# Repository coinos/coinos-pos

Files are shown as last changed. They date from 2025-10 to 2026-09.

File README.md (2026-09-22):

# Coinos Point of Sale Terminal

This device is intended to be used by retail merchants who want to take Bitcoin payments.

When you enter a sale amount in dollars on the device, it will call the Coinos API to generate an invoice.

Once the invoice is paid, the device lights up and displays a checkmark.

You can scroll through past payments and see if tips were added.

This project was inspired by https://github.com/lnbits/lnpos but the software and hardware is different.

## Parts

- [Xiao Seeed ESP32 C3 Development Board](https://www.aliexpress.com/item/1005006979844970.html)
- [3x4 Matrix Switch Keyboard](https://www.aliexpress.com/item/1005007094229478.html)
- [1.54" 4PIN OLED](https://www.aliexpress.com/item/1005009132302307.html)
- [1800mAH LiPo Battery](https://www.aliexpress.com/item/1005009445456523.html)

Design files for the custom PCB and case are included in this repository.

## Setup

Firmware can be installed with a USB C cable either using Arduino IDE or arduino-cli or visit https://coinos.io/flash to flash from the web. The web flasher's "Flash latest release" button installs the firmware published at https://coinos.io/firmware/manifest.json without touching the device's wifi/token config.

To build and publish a new release to the site, run `./publish.sh` (expects a coinos-ui checkout at `~/coinos-ui` or `$COINOS_UI`), then commit and deploy coinos-ui.

Build locally with:

```
arduino-cli compile -b esp32:esp32:esp32c3:CDCOnBoot=cdc --build-property build.partitions=min_spiffs --build-path=build coinos-pos.ino -u -p /dev/ttyACM0
```

`CDCOnBoot=cdc` routes `Serial` to the XIAO's USB-C port so `cat /dev/ttyACM0` shows the device log.

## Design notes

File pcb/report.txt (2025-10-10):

Updated LED from LED to LED1.
Annotation complete.
Annotation complete.

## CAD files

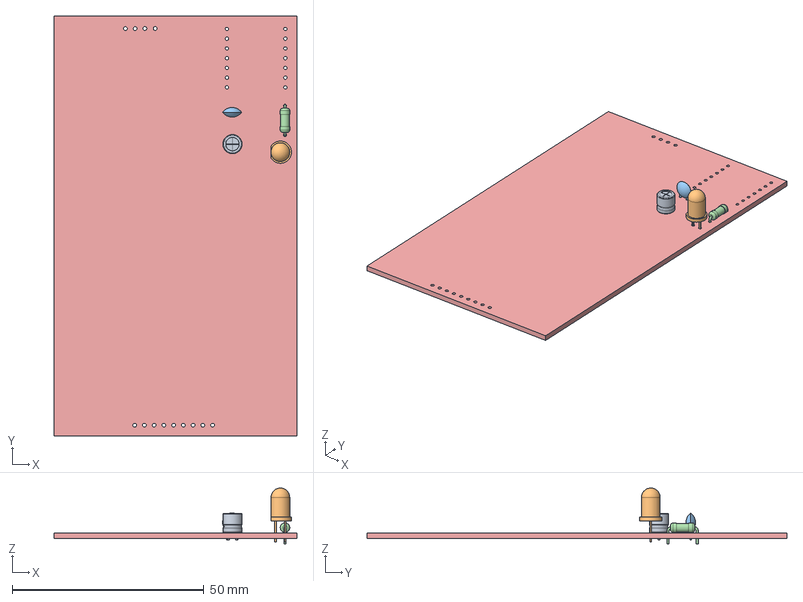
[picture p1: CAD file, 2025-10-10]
pcb/pos.step
63.3 x 109.5 x 14.6 mm
CP_Radial_D5.0mm_P2.00mm
LED_D5.0mm
C_Disc_D5.0mm_W2.5mm_P2.50mm
R_Axial_DIN0207_L6.3mm_D2.5mm_P7.62mm_Horizontal
pos_PCB

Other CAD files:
pcb/pos.stl

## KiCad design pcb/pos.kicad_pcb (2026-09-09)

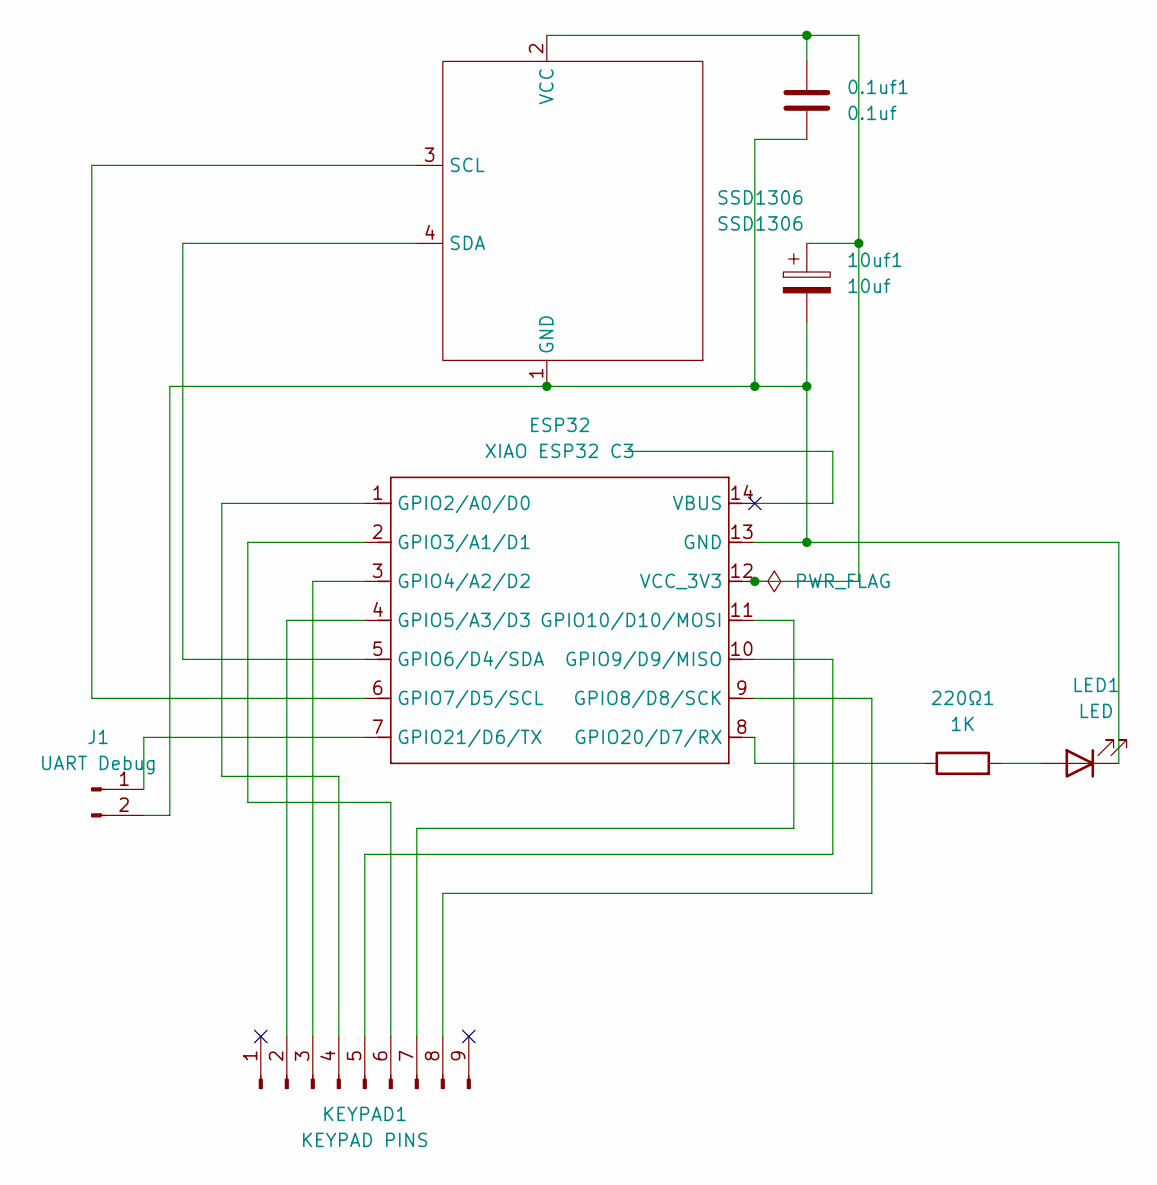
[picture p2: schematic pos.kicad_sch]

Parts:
0.1uf1: 0.1uf; C_Disc_D5.0mm_W2.5mm_P2.50mm
10uf1: 10uf; CP_Radial_D5.0mm_P2.00mm
220Ω1: 1K; R_Axial_DIN0207_L6.3mm_D2.5mm_P7.62mm_Horizontal
ESP32: XIAO ESP32 C3; XIAO-ESP32C3-DIP
J1: UART Debug; PinHeader_1x02_P2.54mm_Vertical
KEYPAD1: KEYPAD PINS; Keypad
LED1: LED; LED_D5.0mm
SSD1306: SSD1306; SD1306

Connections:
unnamed: 0.1uf1.2, 10uf1.2, ESP32.13 (GND), J1.2, LED1.1 (K), SSD1306.1 (GND)
unnamed: ESP32.1 (GPIO2/A0/D0), KEYPAD1.4
unnamed: ESP32.2 (GPIO3/A1/D1), KEYPAD1.6
unnamed: ESP32.3 (GPIO4/A2/D2), KEYPAD1.3
unnamed: ESP32.4 (GPIO5/A3/D3), KEYPAD1.2
unnamed: ESP32.5 (GPIO6/D4/SDA), SSD1306.4 (SDA)
unnamed: ESP32.6 (GPIO7/D5/SCL), SSD1306.3 (SCL)
unnamed: ESP32.9 (GPIO8/D8/SCK), KEYPAD1.8
unnamed: ESP32.10 (GPIO9/D9/MISO), KEYPAD1.5
unnamed: ESP32.11 (GPIO10/D10/MOSI), KEYPAD1.7
unnamed: 220Ω1.1, ESP32.8 (GPIO20/D7/RX)
unnamed: ESP32.7 (GPIO21/D6/TX), J1.1
unnamed: 0.1uf1.1, 10uf1.1, ESP32.12 (VCC_3V3), SSD1306.2 (VCC)
unnamed: 220Ω1.2, LED1.2 (A)

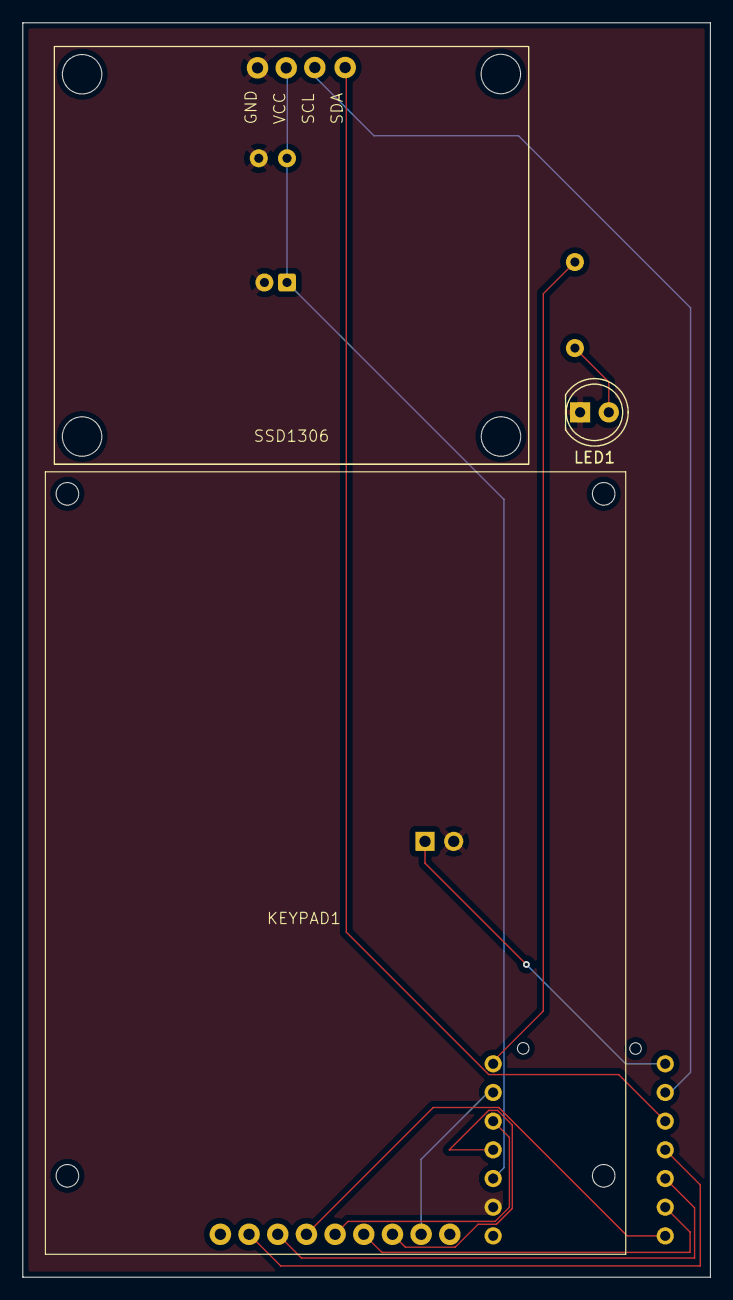
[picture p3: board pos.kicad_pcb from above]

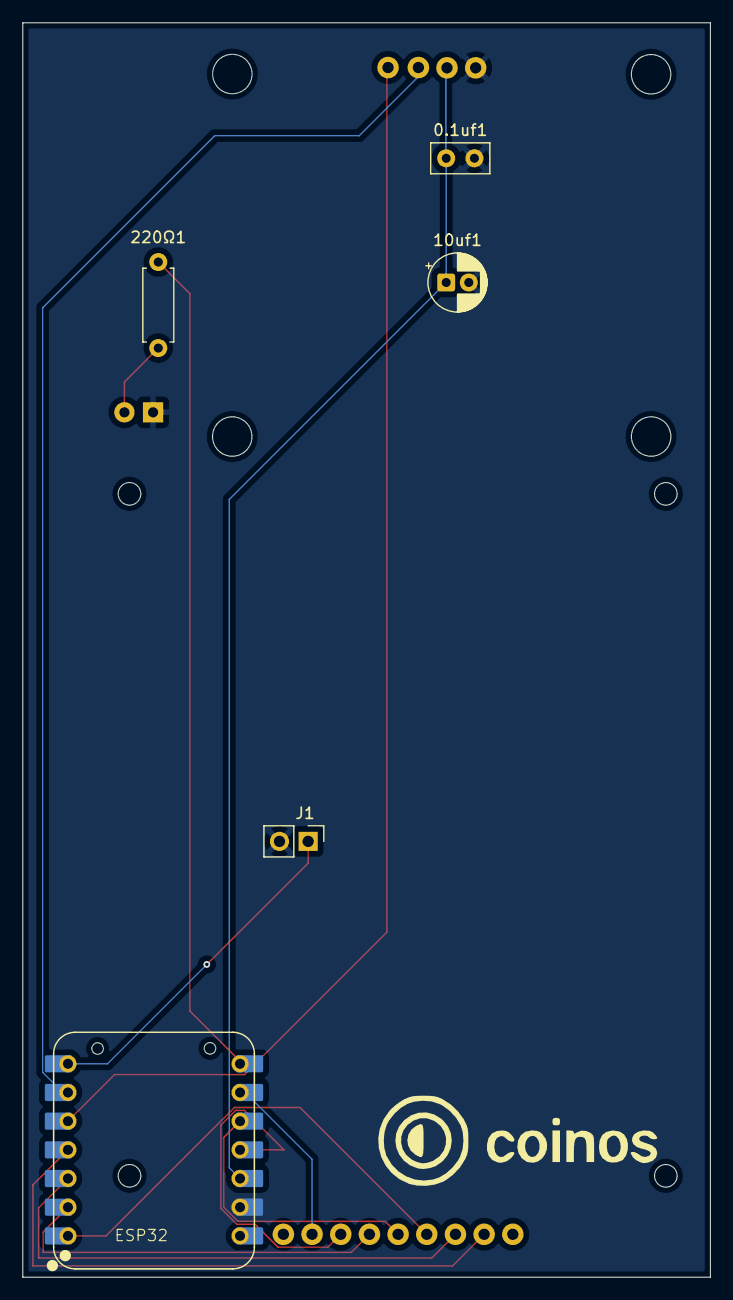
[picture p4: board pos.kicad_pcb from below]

Board: 4 copper layers, 60.9 x 111.1 mm, 8 parts (5 on the bottom side), 14 nets.

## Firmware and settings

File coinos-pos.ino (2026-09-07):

#include <Arduino.h>
#include <Wire.h>
#include <Keypad.h>
#include <WiFi.h>
#include <LittleFS.h>
#include <Adafruit_GFX.h>
#include <Adafruit_SH110X.h>
#include "config.h"
#include "ui.h"
#include "checkmark.h"
#include "storage.h"
#include "wifi_net.h"
#include "payments.h"
#include "nfc.h"
#include "ws.h"
#include "esp_sleep.h"
#include "driver/gpio.h"

// ---- Globals from UI ----
Adafruit_SH1106G display(SCREEN_WIDTH, SCREEN_HEIGHT, &Wire, OLED_RESET_PIN);

// ---- Keypad ----
Keypad keypad = Keypad(makeKeymap(KEYS), (byte*)ROW_PINS, (byte*)COL_PINS, ROWS, COLS);

// ---- State ----
Credentials creds;
String token;
String merchantLnurl;
uint64_t cents = 0;
uint64_t submittedCents = 0;
uint8_t digitsTyped = 0;
String lineStr = "";
String currentInvoiceId = "";
String currentInvoiceFiat = "";
bool invoicePaid = false;


// Auto-submit after 5 seconds of no digit changes
const unsigned long AUTO_SUBMIT_DELAY_MS = 2000;

unsigned long lastAmountChange = 0;
bool autoSubmitDoneForCurrentAmount = false;

Payment history[10];
int historyCount = 0;
int historyIndex = -1;

unsigned long lastHeartbeat = 0;
unsigned long lastActivity = 0;
bool isAsleep = false;

unsigned long lastLog = 0;
const unsigned long LOG_INTERVAL = 5000;

inline void touchActivity() { lastActivity = millis(); }

inline void showAmount(const char* header=nullptr) {
  lineStr = String("$") + formatCents(cents);
  renderLine(lineStr, header);
}

void goToSleep() {
  // Power down peripherals
  oledCommand(0xAE);
  digitalWrite(LED_GREEN_PIN, LOW);
  WiFi.disconnect(true, true);
  WiFi.mode(WIFI_OFF);

  // 1) Bias the keypad for deep sleep:
  //    rows -> OUTPUT LOW (held low during deep sleep)
  for (int i = 0; i < ROWS; ++i) {
    int rp = ROW_PINS[i];
    pinMode(rp, OUTPUT);
    digitalWrite(rp, LOW);
    gpio_hold_en((gpio_num_t)rp);
  }
  gpio_deep_sleep_hold_en();   // enable global hold for held pins

  //    columns -> INPUT_PULLUP (idle HIGH; press pulls LOW via row=LOW)
  for (int i = 0; i < COLS; ++i) {
    pinMode(COL_PINS[i], INPUT_PULLUP);
  }

  // 2) Deep-sleep GPIO wake on every column that can (GPIO0-5 on the C3)
  uint64_t wakeMask = 0;
  for (int i = 0; i < COLS; ++i) {
    int g = COL_PINS[i];
    if (g <= 5) wakeMask |= (1ULL << g);
  }
  esp_deep_sleep_enable_gpio_wakeup(wakeMask, ESP_GPIO_WAKEUP_GPIO_LOW);

  // 3) Also wake every 24 hours
  esp_sleep_enable_timer_wakeup(24ULL * 60ULL * 60ULL * 1000000ULL);

  Serial.println("SLEEP (deep: GPIO 3/5 + 24h)");
  esp_deep_sleep_start();   // never returns
}

void wakeFromSleep() {
  oledCommand(0xAF);
  delay(1);
  display.clearDisplay();
  renderLine("Keypad Ready");
  isAsleep = false;
  lastActivity = millis();
  Serial.println("WAKE");
}

void resetAll() {
  digitalWrite(LED_GREEN_PIN, LOW);
  cents = 0;
  digitsTyped = 0;
  if (currentInvoiceId != "") ws_disconnect();
  currentInvoiceId = "";
  invoicePaid = false;
  historyIndex = -1;
  showAmount("*:Back   #:Enter");

  autoSubmitDoneForCurrentAmount = false;
  lastAmountChange = millis();
}

void renderPayment() {
  if (historyCount == 0) { renderLine("", "No history"); return; }
  if (historyIndex < 0) historyIndex = historyCount - 1;
  if (historyIndex >= historyCount) historyIndex = 0;

  Payment &p = history[historyIndex];

  // Convert sats → fiat cents
  uint64_t satsPaid   = (uint64_t)(p.amount < 0 ? 0 : p.amount);
  uint64_t centsPaid  = roundCentsU64(satsPaid, p.rate);

  uint64_t satsTip    = (uint64_t)(p.tip < 0 ? 0 : p.tip);
  uint64_t centsTip   = roundCentsU64(satsTip, p.rate);

  // Header: local-ish time (keeps your original offset)
  time_t t = (p.created / 1000) - 25200;
  struct tm *createdTime = gmtime(&t);
  char dateString[32], timeString[16], header[48];
  const char* monthAbbrev[] = {"Jan","Feb","Mar","Apr","May","Jun","Jul","Aug","Sep","Oct","Nov","Dec"};
  snprintf(dateString, sizeof(dateString), "%s %d, %d",
           monthAbbrev[createdTime->tm_mon],
           createdTime->tm_mday,
           createdTime->tm_year + 1900);
  int h12 = createdTime->tm_hour % 12; if (h12 == 0) h12 = 12;
  snprintf(timeString, sizeof(timeString), "%d:%02d%s",
           h12, createdTime->tm_min,
           (createdTime->tm_hour < 12) ? "am" : "pm");
  snprintf(header, sizeof(header), "%s %s", dateString, timeString);

  String amountStr = "$" + formatCents(centsPaid);
  String tipStr    = centsTip > 0 ? " +$" + formatCents(centsTip) : "";

  int16_t x1, y1; uint16_t w, hgt;

  display.clearDisplay();
  display.setCursor(0, 0);
  display.setTextSize(1);
  display.print(header);

  display.setTextSize(2);
  display.setCursor(4, 24);
  display.print(amountStr); 

  display.getTextBounds(amountStr.c_str(), 0, 0, &x1, &y1, &w, &hgt);
  display.setTextSize(1);
  display.setCursor(w, 28);
  display.print(tipStr); 

  display.display();
}

bool fetchPayments() {
  if (!ensureWifiConnected(creds, 5000, []() { return keypad.getKey() == '*'; }, 800)) return false;

  HTTPClient http;
  http.setConnectTimeout(3000);
  http.setTimeout(3000);
  http.begin(String(API_HOST) + "/payments?limit=10&received=true");
  http.addHeader("Content-Type", "application/json");
  http.addHeader("Authorization", "Bearer " + token);

  int code = http.GET();
  if (code == HTTP_CODE_OK) {
    String payload = http.getString();
    http.end();

    StaticJsonDocument<256> filter;
    JsonArray flist = filter["payments"].to<JsonArray>();
    JsonObject f = flist.createNestedObject();
    f["id"]=true; f["amount"]=true; f["tip"]=true; f["created"]=true; f["currency"]=true; f["rate"]=true;
    filter["count"]=true;

    StaticJsonDocument<4096> doc;
    auto err = deserializeJson(doc, payload, DeserializationOption::Filter(filter));
    if (err) { Serial.print("payments JSON error: "); Serial.println(err.f_str()); return false; }

    JsonArray arr = doc["payments"].as<JsonArray>();
    historyCount = 0;
    for (JsonObjectConst p : arr) {
      if (historyCount >= (int)(sizeof(history)/sizeof(history[0]))) break;
      Payment &out = history[historyCount++];
      out.id       = p["id"]       | "";
      out.amount   = p["amount"]   | 0LL;
      out.tip      = p["tip"]      | 0LL;
      out.created  = p["created"]  | 0ULL;
      out.currency = p["currency"] | "";
      out.rate     = p["rate"]     | 0.0;
    }
    return true;
  } else {
    http.end();
    return false;
  }
}

void submitInvoice() {
  if (digitsTyped == 0) {
    if (historyIndex < 0) { 
      fetchPayments(); 
      if (historyCount > 0) historyIndex = historyCount - 1; 
    }
    else if (historyCount > 0) historyIndex = (historyIndex - 1 + historyCount) % historyCount;
    renderPayment();
    return;
  }

  String fiat = formatCents(cents);
  if (fiat.toFloat() <= 0 || currentInvoiceId != "") { resetAll(); return; }

  // Bounded: a terminal carried out of wifi range must fail fast and hand
  // the keypad back, not sit on "Submitting..." (it once sat there for the
  // better part of a minute). Worst case here is about 10s — 3s wifi, 3s
  // connect, 3s response — and * cancels the wifi wait.
  if (!ensureWifiConnected(creds, 3000, []() { return keypad.getKey() == '*'; }, 800)) return;

  renderLine(lineStr, "Submitting...");
  submittedCents = cents;

  HTTPClient http;
  http.setConnectTimeout(3000);
  http.setTimeout(3000);
  http.begin(String(API_HOST) + "/invoice");
  http.addHeader("Content-Type", "application/json");
  http.addHeader("Authorization", "Bearer " + token);

  String json = "{\"invoice\":{\"fiat\":\"" + fiat + "\"}}";
  int code = http.POST(json);

  if (code > 0) {
    String payload = http.getString();
    StaticJsonDocument<64> filter; filter["id"] = true;
    DynamicJsonDocument doc(4096);
    auto err = deserializeJson(doc, payload, DeserializationOption::Filter(filter));
    if (!err && doc["id"]) {
      currentInvoiceFiat = fiat;
      currentInvoiceId = (const char*)doc["id"];
      invoicePaid = false;
      ws_connect();
      ws_subscribe(currentInvoiceId);
      renderLine(lineStr, "Waiting for payment..");
    } else {
      renderLine(lineStr, "Invoice error"); delay(800);
    }
  } else {
    renderLine(lineStr, "Submit failed"); delay(800);
  }
  http.end();
}

void handlePayment(long long amount, long long tipSats) {
  if (currentInvoiceId == "" || invoicePaid) return;

  lastActivity = millis();
  invoicePaid = true;
  ws_disconnect();
  digitalWrite(LED_GREEN_PIN, HIGH);

  String header = "$" + currentInvoiceFiat;
  if (tipSats > 0 && submittedCents > 0) {
    double centsPerSat = (double)submittedCents / (double)amount;
    unsigned long long tipCents =
      (unsigned long long) llround((double)tipSats * centsPerSat);
    header += "+$" + formatCents(tipCents);
  }
  startCheckmarkAnimation(header.c_str());
}

// ---- Key handling ----
void onKey(char k) {
  if (isAsleep) wakeFromSleep();

  if (k == '*') {
    // Backspace / history browse
    if (digitsTyped == 0) {
      if (historyIndex < 0) { 
        fetchPayments(); 
        if (historyCount > 0) historyIndex = 0; 
      }
      else if (historyCount > 0) historyIndex = (historyIndex + 1) % historyCount;
      renderPayment();
      return;
    }

    // Backspace a digit
    cents /= 10; 
    digitsTyped--; 
    showAmount("*:Back   #:Enter");
    digitalWrite(LED_GREEN_PIN, LOW);
    currentInvoiceId = ""; 
    invoicePaid = false;

    // amount changed -> reset auto-submit timer
    lastAmountChange = millis();
    autoSubmitDoneForCurrentAmount = false;

    return;
  }

  if (k == '#') {
    digitalWrite(LED_GREEN_PIN, LOW);
    if (currentInvoiceId != "" || invoicePaid) { 
      resetAll(); 
      return; 
    }
    // manual submit: mark as done for this amount
    autoSubmitDoneForCurrentAmount = true;
    submitInvoice();
    return;
  }

  if (k >= '0' && k <= '9') {
    // New digit
    if (currentInvoiceId != "" || invoicePaid) resetAll();
    if (digitsTyped < MAX_DIGITS) {
      uint8_t v = (uint8_t)(k - '0');
      cents = cents * 10 + v;
      digitsTyped++;
      showAmount("*:Back   #:Enter");

      // amount changed -> reset auto-submit timer
      lastAmountChange = millis();
      autoSubmitDoneForCurrentAmount = false;
    }
  }
}

void setup() {
  Serial.begin(115200);
  delay(50);

  if (!LittleFS.begin()) Serial.println("LittleFS mount error");

  gpio_deep_sleep_hold_dis();
  for (int i = 0; i < ROWS; ++i) {
    gpio_hold_dis((gpio_num_t)ROW_PINS[i]);
  }

  // (Optional) check why we woke
  auto cause = esp_sleep_get_wakeup_cause();
  if (cause == ESP_SLEEP_WAKEUP_TIMER) {
    // quick maintenance: WiFi on -> check updates -> WiFi off -> sleep again if idle
  }

  // Load creds (token included in file’s 3rd line)
  if (readCredentials(creds)) {
    token = creds.token;
  } else {
    token = "";
  }

  ui_begin();
  nfc_begin();  // PN532 on shared I2C bus (addr 0x24)
  pinMode(LED_GREEN_PIN, OUTPUT);

  // Fetch username from API to derive LNURL for NFC
  if (token.length() > 0 && ensureWifiConnected(creds, 20000)) {
    HTTPClient http;
    http.begin(String(API_HOST) + "/me");
    http.addHeader("Authorization", "Bearer " + token);
    int code = http.GET();
    if (code == HTTP_CODE_OK) {
      StaticJsonDocument<64> filter; filter["username"] = true;
      StaticJsonDocument<256> doc;
      auto err = deserializeJson(doc, http.getString(), DeserializationOption::Filter(filter));
      if (!err && doc["username"]) {
        String username = (const char*)doc["username"];
        merchantLnurl = nfc_deriveLnurl(username);
        Serial.printf("Merchant: %s\n", username.c_str());
      }
    }
    http.end();

    // Prepare websocket for payment notifications (connects on invoice submit)
    onPaymentReceived = handlePayment;
    ws_init(token);
  }

  resetAll();
  lastActivity = millis();
}

void loop() {
  // Keypad: full-matrix scan so a chord can be recognised. A press is held
  // for a short window before it acts, so the second key of a chord can join
  // it — otherwise # alone would submit a sale before *+# was seen. * and #
  // share a row on different columns, which a diode-less 4x3 matrix reads
  // cleanly (ghosting needs two keys in each of two rows and two columns).
  static char pendingKey = 0;
  static unsigned long pendingAt = 0;
  const unsigned long CHORD_WINDOW_MS = 120;
  if (keypad.getKeys()) {
    for (int i = 0; i < LIST_MAX; i++) {
      Key &k = keypad.key[i];
      if (k.kchar == NO_KEY || !k.stateChanged || k.kstate != PRESSED) continue;
      if (pendingKey) {
        auto chord = [&](char a, char b) {
          return (pendingKey == a && k.kchar == b) || (pendingKey == b && k.kchar == a);
        };
        if (chord('*', '#')) {
          // *+# together: reboot (a stuck terminal has no other way out)
          renderLine("", "Rebooting..");
          delay(300);
          ESP.restart();
        }
        if (chord('0', '#')) {
          // 0+# together: sleep now, exactly as the idle timeout would.
          // A held key pulls its column low, which is the wake source, so
          // wait for both to be released first.
          renderLine("", "Sleeping..");
          unsigned long t0 = millis();
          while (millis() - t0 < 3000) {
            keypad.getKeys();
            bool down = false;
            for (int j = 0; j < LIST_MAX; j++) {
              Key &kk = keypad.key[j];
              if (kk.kchar != NO_KEY && (kk.kstate == PRESSED || kk.kstate == HOLD)) down = true;
            }
            if (!down) break;
            delay(10);
          }
          delay(50);
          goToSleep(); // never returns
        }
        onKey(pendingKey); touchActivity();
      }
      pendingKey = k.kchar;
      pendingAt = millis();
    }
  }
  if (pendingKey && millis() - pendingAt >= CHORD_WINDOW_MS) {
    char key = pendingKey;
    pendingKey = 0;
    onKey(key); touchActivity();
  }

  // Throttled debug
  if (millis() - lastLog >= LOG_INTERVAL) {
    lastLog = millis();
    Serial.printf("idle(ms): %lu  wifi: %s ssid=%s ip=%s\n",
                  millis() - lastActivity,
                  WiFi.status() == WL_CONNECTED ? "up" : "down",
                  creds.ssid.c_str(), WiFi.localIP().toString().c_str());
  }

  unsigned long now = millis();
  unsigned long idle = now - lastActivity;
  unsigned long timeout = (currentInvoiceId == "")
      ? INACTIVITY_NO_INVOICE_MS
      : INACTIVITY_WITH_INVOICE_MS;

  if (!isAsleep) {
    // Is there an amount on screen that we intend to auto-submit?
    bool pendingAutoSubmit =
      (currentInvoiceId == "" && !invoicePaid &&
       digitsTyped > 0 && !autoSubmitDoneForCurrentAmount);

    // --- AUTO-SUBMIT IF AMOUNT UNCHANGED FOR 5s ---
    if (pendingAutoSubmit &&
        (now - lastAmountChange) >= AUTO_SUBMIT_DELAY_MS) {

      autoSubmitDoneForCurrentAmount = true;
      submitInvoice();
      touchActivity(); // so we don't immediately go to sleep
      // NOTE: after this, currentInvoiceId should be non-empty on success,
      // so pendingAutoSubmit will be false on the next loop iteration.
    }
    // ----------------------------------------------

    // NFC: emulate tag with merchant's LNURL while invoice is active
    if (currentInvoiceId != "" && !invoicePaid && merchantLnurl.length() > 0) {
      nfc_emulate(merchantLnurl.c_str());
      if (nfc_poll()) touchActivity();
    } else {
      nfc_stop();
    }

    if (CM.active) {
      renderCheckmarkFrame();
    } else if (idle >= timeout && !pendingAutoSubmit) {
      // Only sleep if there's no auto-submit waiting to happen
      goToSleep();
    }
  }

  // Process websocket events and send heartbeat
  ws_loop();
  if (wsEnabled && now - lastHeartbeat >= 2000) {
    lastHeartbeat = now;
    ws_heartbeat();
  }

  delay(1);
}

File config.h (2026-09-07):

#pragma once

// ===== Hardware config =====
#define LED_GREEN_PIN      20          // your existing pin

// I2C / OLED
#define I2C_SDA_PIN        6
#define I2C_SCL_PIN        7
#define I2C_ADDRESS        0x3C
#define SCREEN_WIDTH       132
#define SCREEN_HEIGHT      64
#define OLED_RESET_PIN     -1

// Keypad. Deep sleep wakes on a COLUMN pulled low, and on the ESP32-C3 only
// GPIO0-5 can wake the chip, so every column should live on one of those.
//   BOARD_REV 1: the first PCB run. Column 0 (keys 1 4 7 *) is on GPIO10
//     and cannot wake the terminal from sleep.
//   BOARD_REV 2: pcb/pos.kicad_sch from 2026-09-07 on — keypad pin 4 and
//     pin 7 swapped between GPIO2 and GPIO10, so every key wakes it.
#ifndef BOARD_REV
#define BOARD_REV 1
#endif
#define ROWS 4
#define COLS 3
#if BOARD_REV >= 2
static const byte ROW_PINS[ROWS] = {4, 8, 10, 9};
static const byte COL_PINS[COLS] = {2, 5, 3};
#else
static const byte ROW_PINS[ROWS] = {4, 8, 2, 9};
static const byte COL_PINS[COLS] = {10, 5, 3};
#endif
static const char KEYS[ROWS][COLS] = {
  {'1','2','3'},
  {'4','5','6'},
  {'7','8','9'},
  {'*','0','#'}
};

// API — the coinos v3 name registrar's POS endpoints (names/server.js in
// coinosv3). The token in config.txt is a POS token minted by the merchant's
// wallet (Settings → payment address → Point of sale), scoped to one name:
// it can ring up sales and watch them settle, never spend.
static const char* API_HOST = "https://names.coinos.io/pos";
#define POS_WS_HOST "names.coinos.io"
#define POS_WS_PATH "/pos/ws"
#define POS_LNURL_BASE "https://names.coinos.io/lnurlp/"

// UX limits
#define MAX_DIGITS           12
#define MAX_LINE             32

// Sleep timeouts
#define INACTIVITY_NO_INVOICE_MS   (600UL * 1000UL)
#define INACTIVITY_WITH_INVOICE_MS (300UL * 1000UL)

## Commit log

2025-10-10 pcb files
    [pos.kicad_pcb, pos.kicad_sch, pos.step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]
2026-09-05 nfc-test: archive reader-mode tap-to-pay experiment
    Standalone serial-only sketch from March 2026: PN532 in reader mode
    pulls the LNURL-withdraw URL a phone's HCE app broadcasts, creates a
    1-sat invoice and settles it via the withdraw callback. Includes the
    RF boost config and a manual APDU exchange that avoids the library's
    64-byte buffer. Kept for reference; the separate PN532 module is not
    planned for future hardware.
    Claude-Session: https://claude.ai/code/session_014gVYGi29FjTeLdNTiutkZx
    [nfc-test.ino]
2026-09-05 ws: subscribe without login, send Accept header, log socket errors
    Two things kept payment notifications from reaching the device:
    - The server closed the socket a second after a login with the
    read-only token the web flasher hands out, dropping the invoice
    subscription. Subscriptions are unauthenticated, so stop logging in
    and send token-less heartbeats instead. Works on any server version.
    - Cloudflare's managed WAF rule "Anomaly:Header:Accept - Missing or
    Empty" answers the library's handshake with a 403 challenge because
    it sends no Accept header. Add one via setExtraHeaders.
    Also surface WStype_ERROR on the serial log.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
2026-09-05 publish.sh: build and publish firmware to the coinos.io web flasher
    Copies bootloader, partition table, boot_app0 and the app image into
    coinos-ui/static/firmware with a manifest.json (version from commit
    date + short hash) that the /pos flasher's "Flash latest release"
    button consumes. README documents the flow and the CDCOnBoot build
    option for USB serial logging.
    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
2026-09-05 log: include wifi state, SSID and IP in the periodic serial line
    The merchant lookup is the only wifi evidence on serial and it happens
    before a host can attach, so a device's wifi state was unobservable
    after boot.
    Claude-Session: https://claude.ai/code/session_01VMi2Y1oKPZ3TeeFmLej47y
2026-09-06 backend: talk to the coinos v3 registrar's POS endpoints
    API_HOST moves to names.coinos.io/pos (same /invoice, /me and /payments
    shapes), the payment socket is /pos/ws authenticated by the POS token on
    the URL, and the NFC LNURL points at the registrar's lnurlp for the
    merchant's name, which pins the sale the terminal just rang up.
    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
2026-09-07 submit: fail within ~10s and let * cancel the wifi wait
    Carrying the terminal out of wifi range left it on "Submitting..." for
    most of a minute with a dead keypad: a 20s reconnect wait plus a 3s
    failure hold plus default HTTP timeouts. Now 3s wifi (cancellable with *),
    3s connect, 3s response, 0.8s failure hold; history fetch likewise.
    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
    [coinos-pos.ino]
2026-09-07 keypad: full-matrix scan with a chord window; *+# reboots
    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
    [coinos-pos.ino]
2026-09-07 sleep: arm every wake-capable column; document the GPIO0-5 wake limit
    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
2026-09-07 pcb: swap keypad pins 4 and 7 between GPIO2 and GPIO10 so every key wakes the terminal
    Only GPIO0-5 can wake the ESP32-C3 from deep sleep and column 0 (keys
    1 4 7 *) sat on GPIO10. The schematic now routes keypad pin 4 (column 0)
    to GPIO2 and pin 7 (row 2) to GPIO10; the PCB still needs "Update PCB
    from schematic" and two traces rerouted. Firmware picks the pin map by
    BOARD_REV (1 = first run, default; 2 = this revision).
    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
    [pos.kicad_sch]
2026-09-07 gitignore: track the KiCad footprint library table; ignore caches, backups and locks
    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
2026-09-07 pcb: adopt the live KiCad project (was ~/pos) and the v1/v2 fab gerber zips
    ~/pos is now a symlink into the repo so KiCad's recent-projects entries
    keep working and every save is versioned. The board file carries the
    reference re-annotation (KEYPAD1, LED1) from today's netlist sync; the
    keypad pin swap still needs Update PCB from Schematic plus two traces.
    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
    [pos.kicad_pcb]
2026-09-09 pcb: reroute keypad pins 4 and 7 for revision 2
    [pos.kicad_pcb]
